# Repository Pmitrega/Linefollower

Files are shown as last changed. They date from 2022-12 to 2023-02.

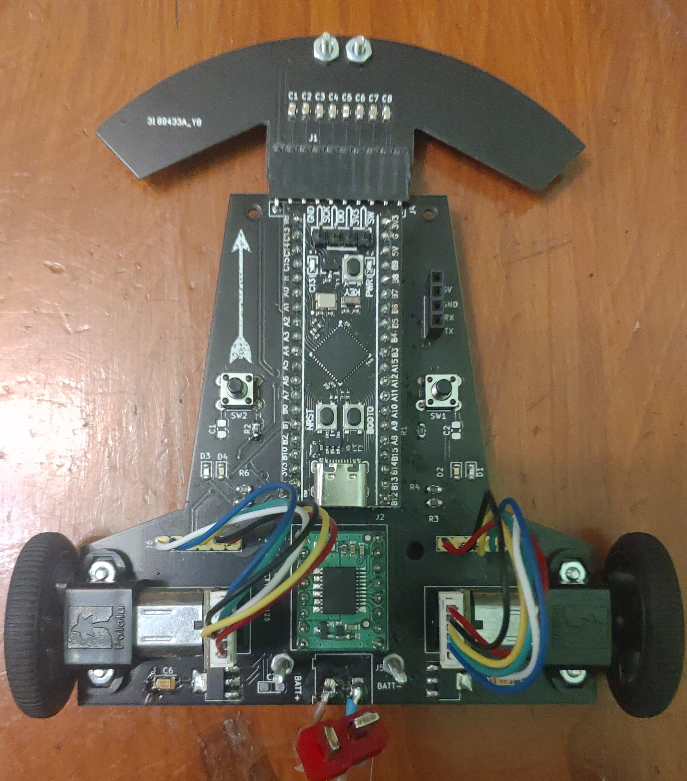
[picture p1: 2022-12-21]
photos/assembled.jpg

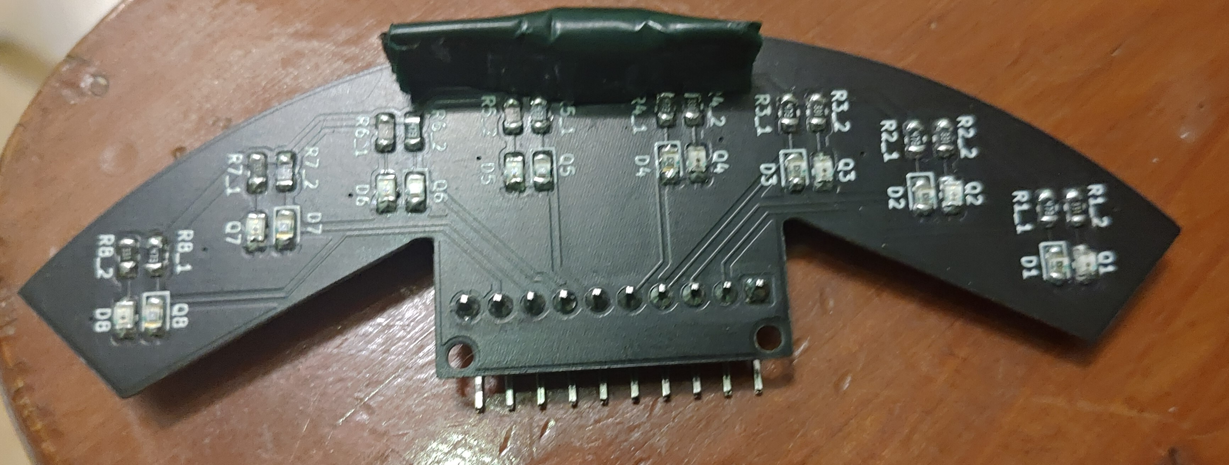
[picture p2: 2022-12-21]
photos/sensors.jpg

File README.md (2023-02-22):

# Linefollower
Robot is made on self-designed board with attached self-designed reflective sensors using ir diode and phototransistor.
For this moment there is algorithm estimating angle error, velocity control using PI controller, and angle P controller to follow line. Succesfully tested on track.
Can be also controlled using bluetooth with xbox controller by sending ascii commands.

Project is finnished, probably won't be updated. Contiunation of LF project is under this link: [Linefollower_V2](https://github.com/Pmitrega/Linefollower_V2)

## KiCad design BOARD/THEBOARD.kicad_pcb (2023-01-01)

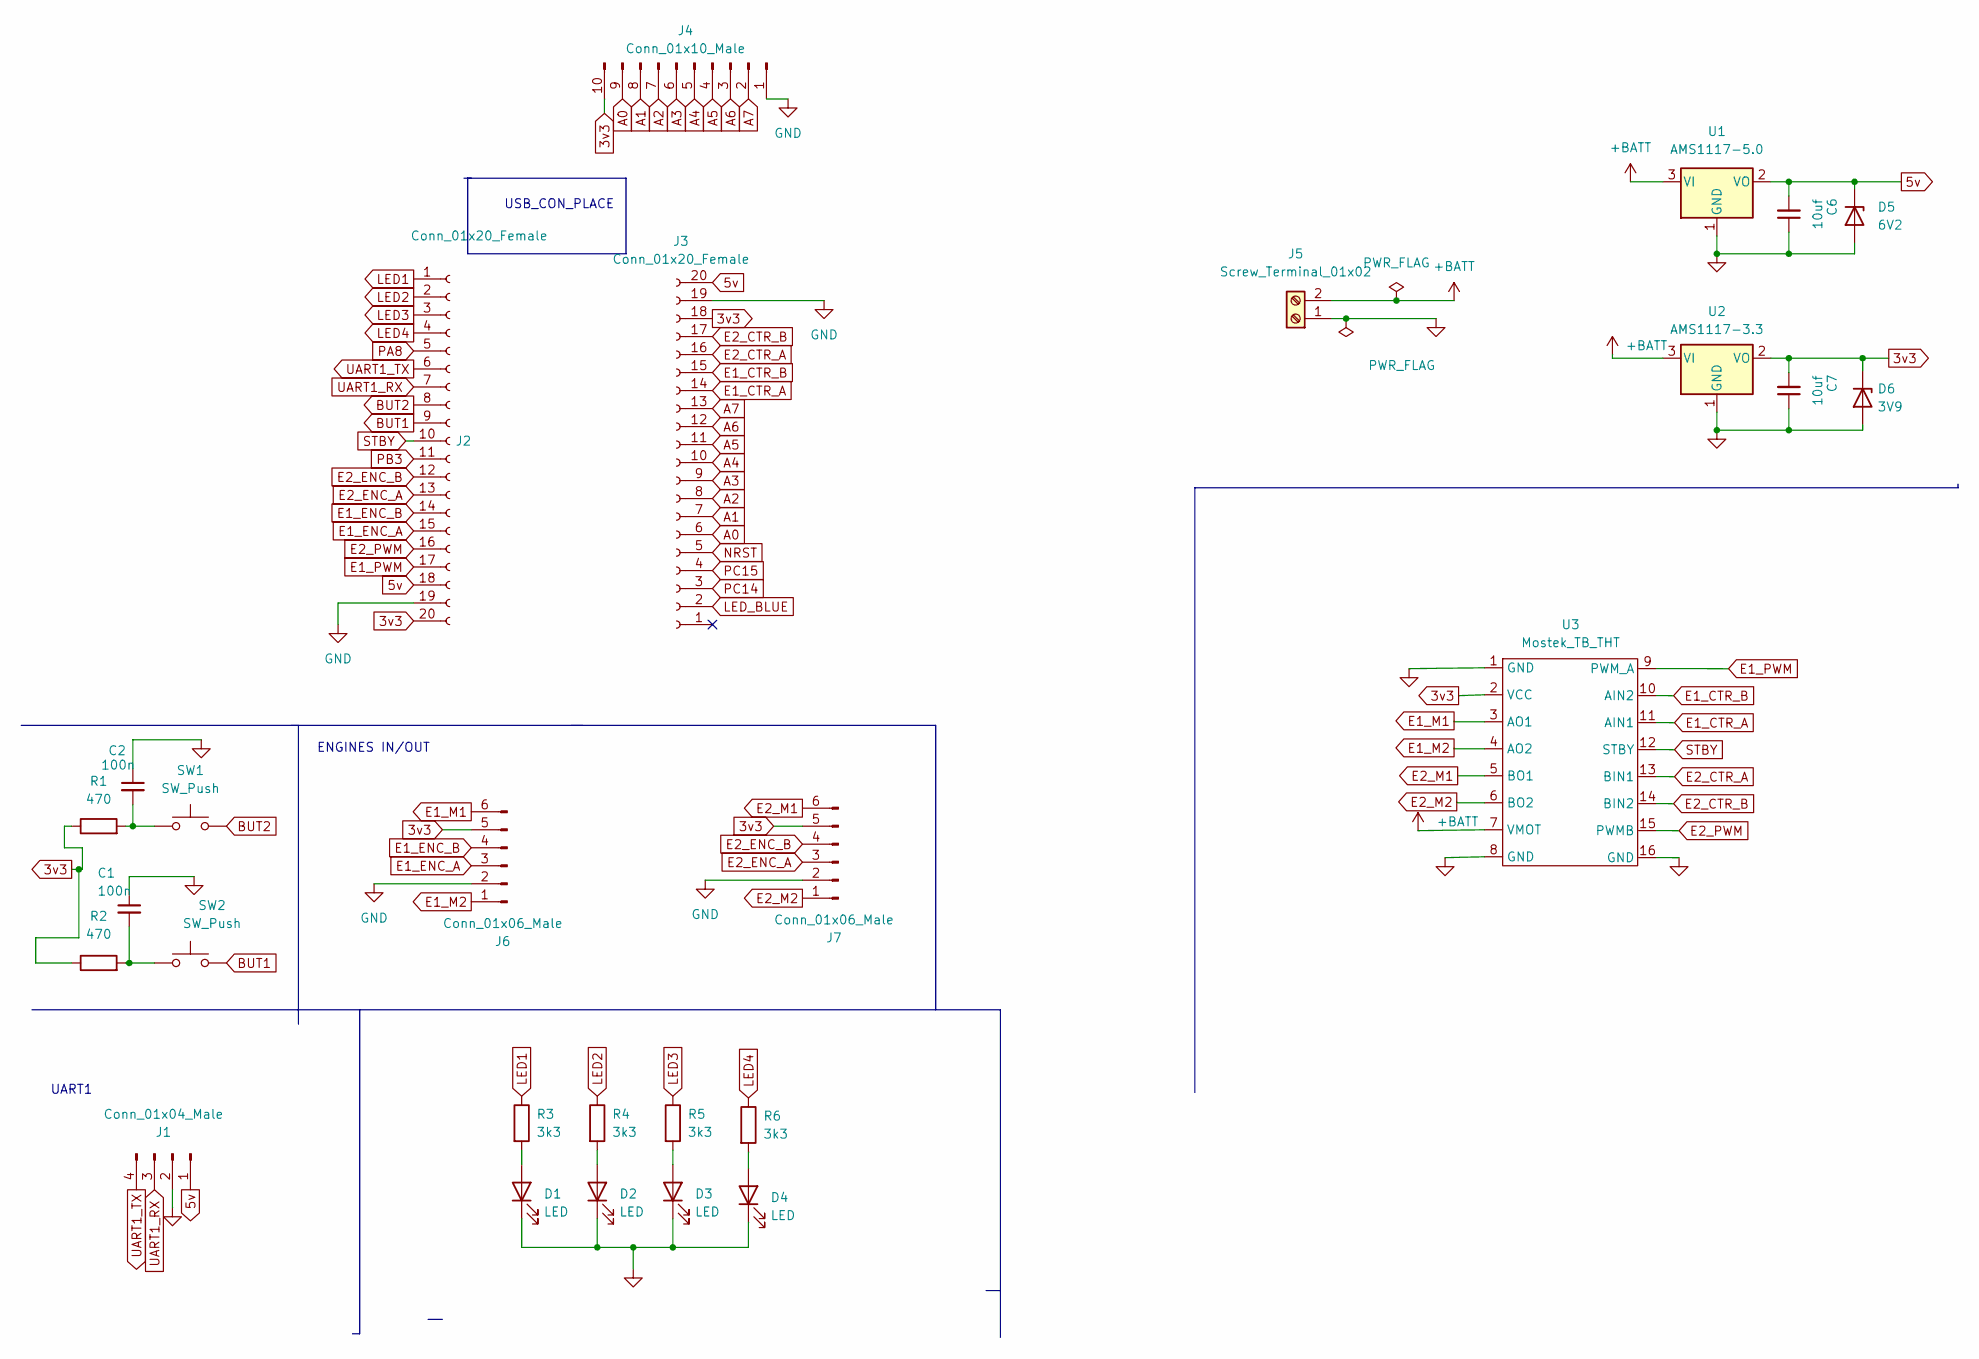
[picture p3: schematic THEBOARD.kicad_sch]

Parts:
C1, C2: 100n; C_0805_2012Metric_Pad1.18x1.45mm_HandSolder
C6, C7: 10uf; CP_EIA-3216-18_Kemet-A_Pad1.58x1.35mm_HandSolder
D1, D2, D3, D4: LED; D_0805_2012Metric_Pad1.15x1.40mm_HandSolder
D5: 6V2; D_MiniMELF_Handsoldering
D6: 3V9; D_MiniMELF_Handsoldering
J1: Conn_01x04_Male; PinSocket_1x04_P2.54mm_Vertical
J2, J3: Conn_01x20_Female; PinSocket_1x20_P2.54mm_Vertical
J4: Conn_01x10_Male; PinSocket_1x10_P2.54mm_Vertical
J5: Screw_Terminal_01x02; TerminalBlock_Altech_AK300-2_P5.00mm
J6, J7: Conn_01x06_Male; PinSocket_1x06_P2.54mm_Vertical
R1, R2: 470; R_0805_2012Metric_Pad1.20x1.40mm_HandSolder
R3, R4, R5, R6: 3k3; R_0805_2012Metric_Pad1.20x1.40mm_HandSolder
SW1, SW2: SW_Push; SW_PUSH_6mm
U1: AMS1117-5.0; SOT-223-3_TabPin2
U2: AMS1117-3.3; SOT-223-3_TabPin2
U3: Mostek_TB_THT; H_BRIDGE

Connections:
3v3: C7.2, D6.1 (K), J2.20, J3.18, J4.10, J6.5, J7.5, R1.1, R2.1, U2.2 (VO), U3.2 (VCC)
5v: C6.2, D5.1 (K), J1.1, J2.18, J3.20, U1.2 (VO)
+BATT: J5.2, U1.3 (VI), U2.3 (VI), U3.7 (VMOT); also elsewhere on the board
A0: J3.6, J4.9
A1: J3.7, J4.8
A2: J3.8, J4.7
A3: J3.9, J4.6
A4: J3.10, J4.5
A5: J3.11, J4.4
A6: J3.12, J4.3
A7: J3.13, J4.2
BUT1: J2.9, SW2.2
BUT2: J2.8, SW1.2
E1_CTR_A: J3.14, U3.11 (AIN1)
E1_CTR_B: J3.15, U3.10 (AIN2)
E1_ENC_A: J2.15, J6.3
E1_ENC_B: J2.14, J6.4
E1_M1: J6.6, U3.3 (AO1)
E1_M2: J6.1, U3.4 (AO2)
E1_PWM: J2.17, U3.9 (PWM_A)
E2_CTR_A: J3.16, U3.13 (BIN1)
E2_CTR_B: J3.17, U3.14 (BIN2)
E2_ENC_A: J2.13, J7.3
E2_ENC_B: J2.12, J7.4
E2_M1: J7.6, U3.5 (BO1)
E2_M2: J7.1, U3.6 (BO2)
E2_PWM: J2.16, U3.15 (PWMB)
GND: C1.1, C2.1, C6.1, C7.1, D1.1 (K), D2.1 (K), D3.1 (K), D4.1 (K), D5.2 (A), D6.2 (A), J1.2, J2.19, J3.19, J4.1, J5.1, J6.2, J7.2, U1.1 (GND), U2.1 (GND), U3.1 (GND), U3.8 (GND), U3.16 (GND); also elsewhere on the board
LED1: J2.1, R3.1
LED2: J2.2, R4.1
LED3: J2.3, R5.1
LED4: J2.4, R6.1
LED_BLUE: J3.2
NRST: J3.5
unnamed: C1.2, R2.2, SW2.1
unnamed: C2.2, R1.2, SW1.1
unnamed: D1.2 (A), R3.2
unnamed: D2.2 (A), R4.2
unnamed: D3.2 (A), R5.2
unnamed: D4.2 (A), R6.2
PA8: J2.5
PB3: J2.11
PC14: J3.3
PC15: J3.4
STBY: J2.10, U3.12 (STBY)
UART1_RX: J1.3, J2.7
UART1_TX: J1.4, J2.6

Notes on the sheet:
UART1
USB_CON_PLACE
ENGINES IN/OUT

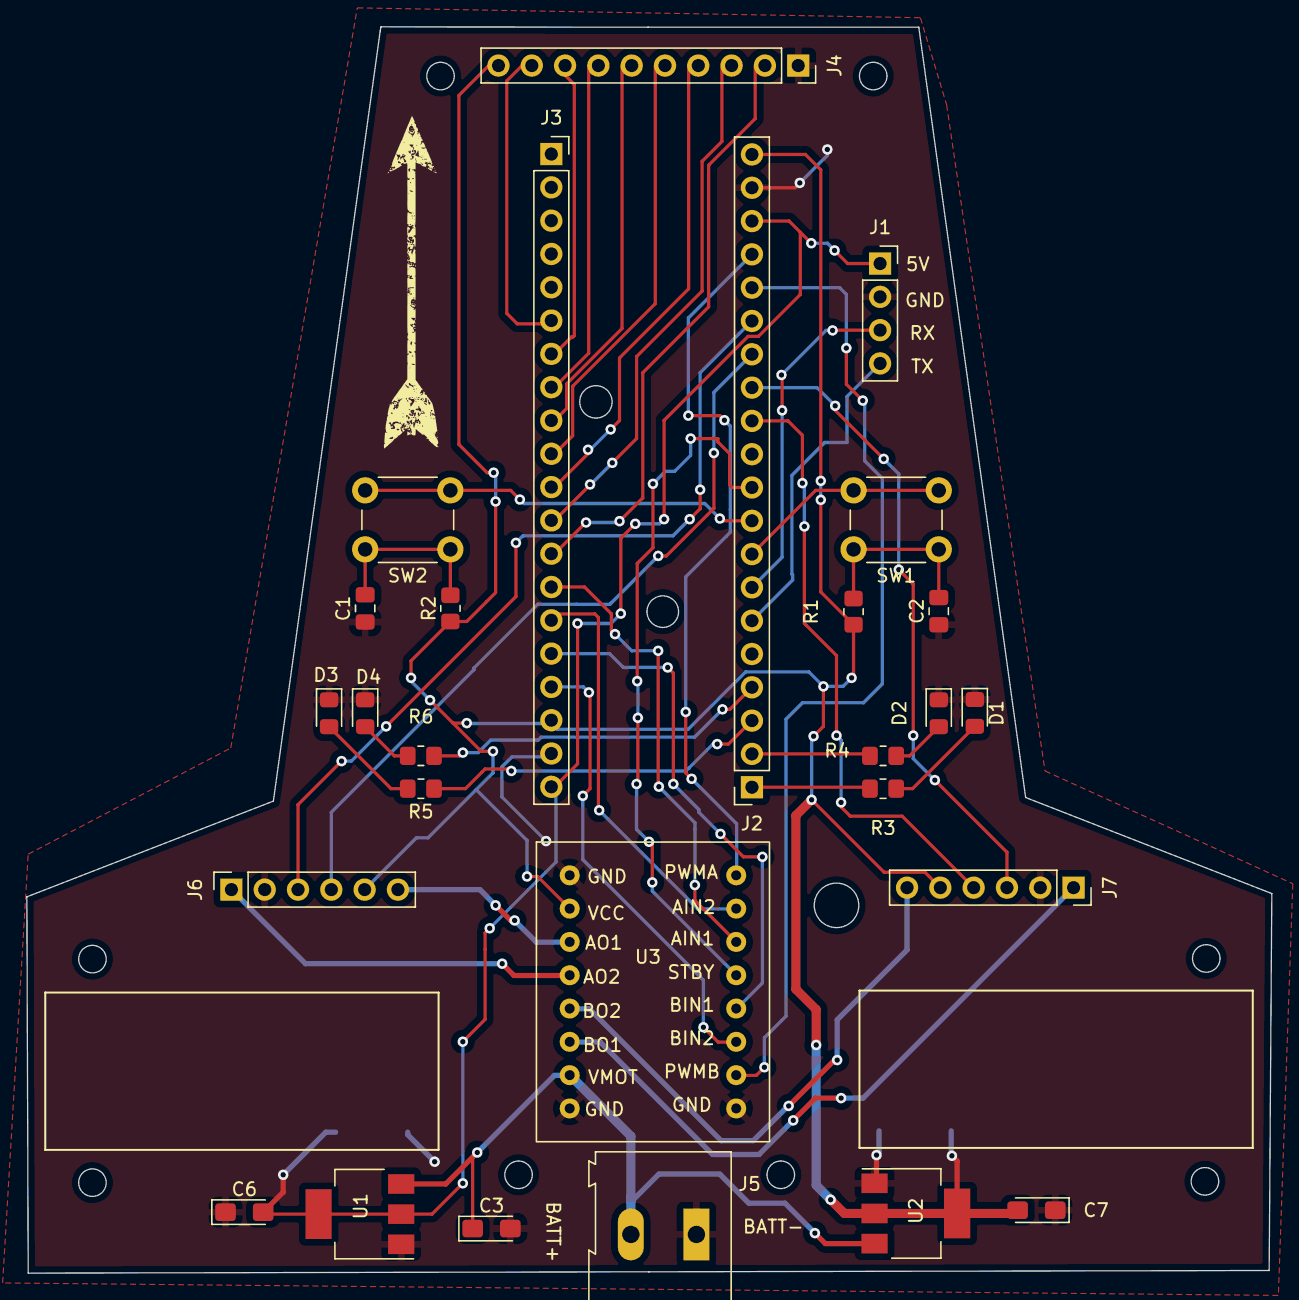
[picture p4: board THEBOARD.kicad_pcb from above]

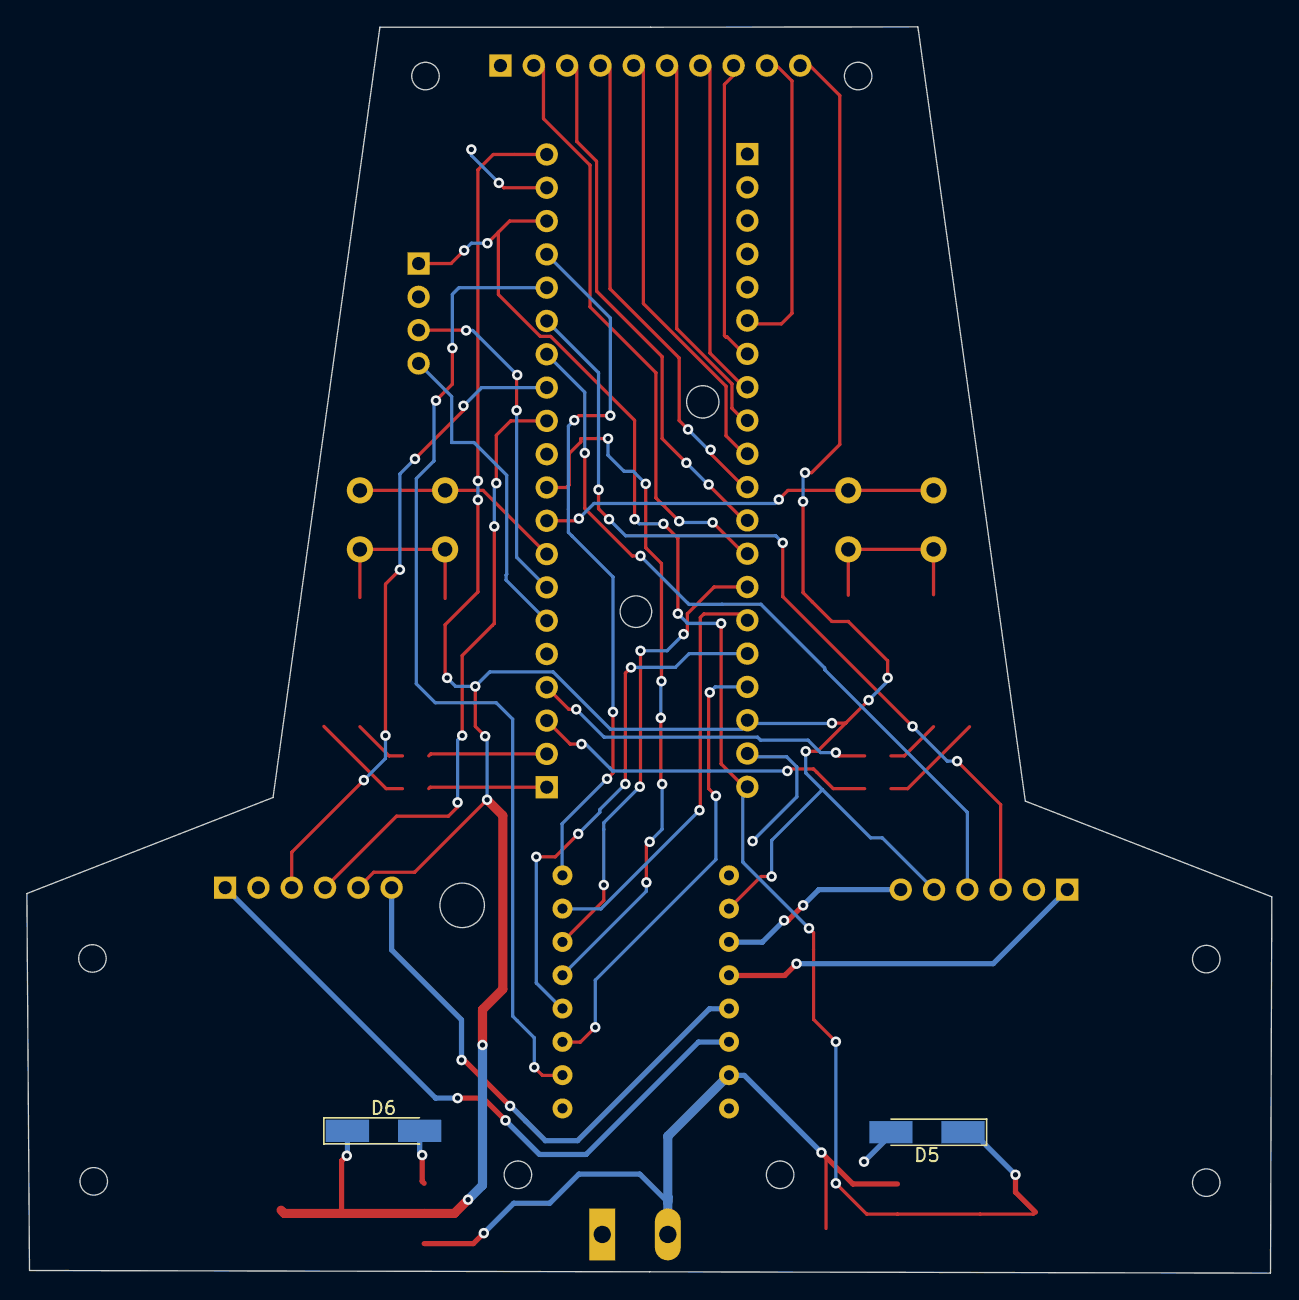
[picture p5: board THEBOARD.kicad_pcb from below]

Board: 2 copper layers, 95.0 x 95.0 mm, 29 parts (2 on the bottom side), 41 nets.

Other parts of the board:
C3: 10uf; CP_EIA-3216-18_Kemet-A_Pad1.58x1.35mm_HandSolder

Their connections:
+BATT: C3.1; also elsewhere on the board
GND: C3.2; also elsewhere on the board

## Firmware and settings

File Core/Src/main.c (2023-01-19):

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
/* Includes ------------------------------------------------------------------*/
#include "main.h"

/* USER CODE BEGIN Includes */
#include "motors.h"
#include "sensors.h"
#include "uart_handler.h"
/* USER CODE END Includes */

/* USER CODE BEGIN PD */
#define P_velocity 13

/* USER CODE END PD */

ADC_HandleTypeDef hadc1;
DMA_HandleTypeDef hdma_adc1;

TIM_HandleTypeDef htim3;
TIM_HandleTypeDef htim4;
TIM_HandleTypeDef htim5;
TIM_HandleTypeDef htim9;
TIM_HandleTypeDef htim10;
TIM_HandleTypeDef htim11;

UART_HandleTypeDef huart1;

/* USER CODE BEGIN PV */
int velocity_LEFT;
int velocity_RIGHT;
int velocity_ARRAY_LEFT[4] = {0,0,0,0};
int velocity_ARRAY_RIGHT[4] = {0,0,0,0};
int flt_cnt = 0;
extern uint16_t sensor_readings[8];
int angle = 0;
int BASE_SPEED = 0;
extern uint8_t recieve;
int auto_control_flag = 0;
/* USER CODE END PV */

void SystemClock_Config(void);
static void MX_GPIO_Init(void);
static void MX_DMA_Init(void);
static void MX_TIM10_Init(void);
static void MX_TIM11_Init(void);
static void MX_TIM3_Init(void);
static void MX_TIM4_Init(void);
static void MX_ADC1_Init(void);
static void MX_USART1_UART_Init(void);
static void MX_TIM9_Init(void);
static void MX_TIM5_Init(void);
/* USER CODE BEGIN 0 */

int get_average(int* arr,int size){
  int avr = 0;
  int div = size;
  for(int i=0;i<size;i++){
    if(arr[i]>2000){
      div--;
    }
    else
      avr+=arr[i];
  }
  return avr/div;
}
void HAL_TIM_PeriodElapsedCallback(TIM_HandleTypeDef *htim){
  static uint16_t last_enc_LEFT = 32000;
  static uint16_t last_enc_RIGHT = 32000;
  static int velocity_LEFT_TMP;
  static int velocity_RIGHT_TMP;
  if(htim == &htim9){
    velocity_LEFT = (int)(((int)last_enc_LEFT - ENCODER_LEFT)*CONVERSION_COEFFICIENT);
    velocity_RIGHT =(int)((-(int)last_enc_RIGHT + ENCODER_RIGHT)*CONVERSION_COEFFICIENT);
    // velocity_ARRAY_LEFT[flt_cnt%4] = velocity_LEFT_TMP;
    // velocity_ARRAY_RIGHT[flt_cnt%4] = velocity_RIGHT_TMP;
    // velocity_LEFT = get_average(velocity_ARRAY_LEFT, 4);
    // velocity_RIGHT = get_average(velocity_ARRAY_RIGHT, 4);
    // velocity_LEFT = velocity_LEFT_TMP;
    // velocity_LEFT = velocity_RIGHT_TMP;
    flt_cnt+=1;
    last_enc_LEFT = ENCODER_LEFT;
    last_enc_RIGHT = ENCODER_RIGHT;
  }
  if(htim == &htim5){
    if(auto_control_flag){
      angle = estimate_angle(sensor_readings);
      set_velocity(MOTOR_LEFT,P_velocity*angle+BASE_SPEED);
      set_velocity(MOTOR_RIGHT, -P_velocity*angle+BASE_SPEED);
  }
      velocity_pid();
  }
}

void led_check(){
  HAL_GPIO_WritePin(GPIOB, LED_RED1_Pin,1);
  HAL_Delay(200);
  HAL_GPIO_WritePin(GPIOB, LED_BLUE1_Pin, 1);
  HAL_Delay(200);
  HAL_GPIO_WritePin(GPIOB, LED_BLUE2_Pin, 1);
  HAL_Delay(200);
  HAL_GPIO_WritePin(GPIOB, LED_RED2_Pin, 1);
  HAL_Delay(200);
  HAL_GPIO_WritePin(GPIOB, LED_RED1_Pin,0);
  HAL_Delay(200);
  HAL_GPIO_WritePin(GPIOB, LED_BLUE1_Pin, 0);
  HAL_Delay(200);
  HAL_GPIO_WritePin(GPIOB, LED_BLUE2_Pin, 0);
  HAL_Delay(200);
  HAL_GPIO_WritePin(GPIOB, LED_RED2_Pin, 0);
}

/* USER CODE END 0 */

/**
  * @brief  The application entry point.
  * @retval int
  */
int main(void)
{
  /* MCU Configuration--------------------------------------------------------*/

  /* Reset of all peripherals, Initializes the Flash interface and the Systick. */
  HAL_Init();

  /* Configure the system clock */
  SystemClock_Config();

  /* Initialize all configured peripherals */
  MX_GPIO_Init();
  MX_DMA_Init();
  MX_TIM10_Init();
  MX_TIM11_Init();
  MX_TIM3_Init();
  MX_TIM4_Init();
  MX_ADC1_Init();
  MX_USART1_UART_Init();
  MX_TIM9_Init();
  MX_TIM5_Init();
  /* USER CODE BEGIN 2 */
  HAL_TIM_Base_Start_IT(&htim9);
  HAL_TIM_PWM_Start(&htim10, TIM_CHANNEL_1);
  HAL_TIM_PWM_Start(&htim11, TIM_CHANNEL_1);
  TIM3->CNT = 32000;
  TIM4->CNT = 32000;
  char buffer[30];
  int l;
  HAL_TIM_Encoder_Start(&htim3, TIM_CHANNEL_ALL);
  HAL_TIM_Encoder_Start(&htim4, TIM_CHANNEL_ALL);
  HAL_GPIO_WritePin(STBY_GPIO_Port, STBY_Pin, 1);
  HAL_GPIO_WritePin(STBY_GPIO_Port, STBY_Pin, 1);
  led_check();
  HAL_UART_Receive_IT(&huart1, &recieve, 1);
  HAL_ADC_Start_DMA(&hadc1,  (uint32_t *)sensor_readings, 8);
  HAL_Delay(200);
  HAL_TIM_Base_Start_IT(&htim5);

  /* USER CODE END 2 */

  /* Infinite loop */
  /* USER CODE BEGIN WHILE */
  while (1)
  {   
      HAL_Delay(300);
      if(HAL_GPIO_ReadPin(SW2_GPIO_Port, SW2_Pin)){
        auto_control_flag = 1;
        BASE_SPEED = 120;
      }
      //l = sprintf(buffer, "%d %d %d %d %d %d %d %d\n",sensor_readings[0],sensor_readings[1],sensor_readings[2],sensor_readings[3],sensor_readings[4],sensor_readings[5],sensor_readings[6],sensor_readings[7]);
      // l = sprintf(buffer, "%d %d %d\n", velocity_LEFT, velocity_RIGHT, estimate_angle(sensor_readings));
      // HAL_UART_Transmit(&huart1, buffer, l, 100);
      //HAL_Delay(3);
    /* USER CODE END WHILE */

    /* USER CODE BEGIN 3 */
  }
  /* USER CODE END 3 */
}

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


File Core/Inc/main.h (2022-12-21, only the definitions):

#define LED_ONBOARD_Pin GPIO_PIN_13
#define LED_ONBOARD_GPIO_Port GPIOC
#define AIN1_Pin GPIO_PIN_0
#define AIN1_GPIO_Port GPIOB
#define AIN2_Pin GPIO_PIN_1
#define AIN2_GPIO_Port GPIOB
#define BIN1_Pin GPIO_PIN_2
#define BIN1_GPIO_Port GPIOB
#define BIN2_Pin GPIO_PIN_10
#define BIN2_GPIO_Port GPIOB
#define LED_RED2_Pin GPIO_PIN_12
#define LED_RED2_GPIO_Port GPIOB
#define LED_BLUE2_Pin GPIO_PIN_13
#define LED_BLUE2_GPIO_Port GPIOB
#define LED_RED1_Pin GPIO_PIN_14
#define LED_RED1_GPIO_Port GPIOB
#define LED_BLUE1_Pin GPIO_PIN_15
#define LED_BLUE1_GPIO_Port GPIOB
#define SW1_Pin GPIO_PIN_11
#define SW1_GPIO_Port GPIOA
#define SW2_Pin GPIO_PIN_12
#define SW2_GPIO_Port GPIOA
#define STBY_Pin GPIO_PIN_15
#define STBY_GPIO_Port GPIOA
#define PWMB_Pin GPIO_PIN_8
#define PWMB_GPIO_Port GPIOB
#define PWMA_Pin GPIO_PIN_9
#define PWMA_GPIO_Port GPIOB

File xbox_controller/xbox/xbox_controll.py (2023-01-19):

import time
import serial
from inputs import get_gamepad
import math
import threading

class XboxController(object):
    MAX_TRIG_VAL = math.pow(2, 8)
    MAX_JOY_VAL = math.pow(2, 15)

    def __init__(self):

        self.LeftJoystickY = 0
        self.LeftJoystickX = 0
        self.RightJoystickY = 0
        self.RightJoystickX = 0
        self.LeftTrigger = 0
        self.RightTrigger = 0
        self.LeftBumper = 0
        self.RightBumper = 0
        self.A = 0
        self.X = 0
        self.Y = 0
        self.B = 0
        self.LeftThumb = 0
        self.RightThumb = 0
        self.Back = 0
        self.Start = 0
        self.LeftDPad = 0
        self.RightDPad = 0
        self.UpDPad = 0
        self.DownDPad = 0

        self._monitor_thread = threading.Thread(target=self._monitor_controller, args=())
        self._monitor_thread.daemon = True
        self._monitor_thread.start()


    def read(self): # return the buttons/triggers that you care about in this methode
        x = self.LeftJoystickX
        y = self.LeftJoystickY
        a = self.RightJoystickY
        b = self.RightJoystickX
        return [x, y, a, b]


    def _monitor_controller(self):
        while True:
            events = get_gamepad()
            for event in events:
                if event.code == 'ABS_Y':
                    self.LeftJoystickY = event.state / XboxController.MAX_JOY_VAL # normalize between -1 and 1
                elif event.code == 'ABS_X':
                    self.LeftJoystickX = event.state / XboxController.MAX_JOY_VAL # normalize between -1 and 1
                elif event.code == 'ABS_RY':
                    self.RightJoystickY = event.state / XboxController.MAX_JOY_VAL # normalize between -1 and 1
                elif event.code == 'ABS_RX':
                    self.RightJoystickX = event.state / XboxController.MAX_JOY_VAL # normalize between -1 and 1
                elif event.code == 'ABS_Z':
                    self.LeftTrigger = event.state / XboxController.MAX_TRIG_VAL # normalize between 0 and 1
                elif event.code == 'ABS_RZ':
                    self.RightTrigger = event.state / XboxController.MAX_TRIG_VAL # normalize between 0 and 1
                elif event.code == 'BTN_TL':
                    self.LeftBumper = event.state
                elif event.code == 'BTN_TR':
                    self.RightBumper = event.state
                elif event.code == 'BTN_SOUTH':
                    self.A = event.state
                elif event.code == 'BTN_NORTH':
                    self.Y = event.state #previously switched with X
                elif event.code == 'BTN_WEST':
                    self.X = event.state #previously switched with Y
                elif event.code == 'BTN_EAST':
                    self.B = event.state
                elif event.code == 'BTN_THUMBL':
                    self.LeftThumb = event.state
                elif event.code == 'BTN_THUMBR':
                    self.RightThumb = event.state
                elif event.code == 'BTN_SELECT':
                    self.Back = event.state
                elif event.code == 'BTN_START':
                    self.Start = event.state
                elif event.code == 'BTN_TRIGGER_HAPPY1':
                    self.LeftDPad = event.state
                elif event.code == 'BTN_TRIGGER_HAPPY2':
                    self.RightDPad = event.state
                elif event.code == 'BTN_TRIGGER_HAPPY3':
                    self.UpDPad = event.state
                elif event.code == 'BTN_TRIGGER_HAPPY4':
                    self.DownDPad = event.state


'''
Here base velocity parameters are set
'''
BASE_VELOCITY = 80
BASE_TURN_VELOCITY = 40

if __name__ == '__main__':
    joy = XboxController()
    ser = serial.Serial('COM5', 9600, timeout = 6)
    while True:
        '''
        values are are taken from right joystick - up and down is linear velocity - right and left is turning speed
        '''
        cmd = ""
        cmd = cmd+"l" + str(int(BASE_VELOCITY*joy.read()[2]) + BASE_TURN_VELOCITY*joy.read()[3]) + "r" + str(int(BASE_VELOCITY*joy.read()[2]) - BASE_TURN_VELOCITY*joy.read()[3]) + " "
        ser.write(cmd.encode())
        if joy.A == 1:
            '''
            Here is command to change to automatic mode with base speed of 120. LF start following line. This command can be sent again to go back to manual mode.
            sleep prevents from sending multiple time this command.
            '''
            ser.write("a120 ".encode())
            time.sleep(0.3)
        time.sleep(0.03)
        # while ser.in_waiting:
        #     print(ser.readline())

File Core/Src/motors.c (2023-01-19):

#include "motors.h"
#include "string.h"
#include "stdio.h"
#include "main.h"
extern UART_HandleTypeDef huart1;
extern int velocity_LEFT;
extern int velocity_RIGHT;
int desired_velocity_left;
int desired_velocity_right;
int set_PWM(enum Motor mot, uint16_t value){
    if(value>1000){
        return -1;
    }
    if(mot == MOTOR_LEFT){
        TIM11->CCR1 = value;
    }
    else if (mot == MOTOR_RIGHT)
    {
        TIM10->CCR1 = value;
    }
    return 0;
    
}
int set_direction(enum Motor mot,enum Direction dir){

    if(mot == MOTOR_LEFT){
        if(dir == BACKWARD){
            HAL_GPIO_WritePin(AIN1_GPIO_Port, AIN1_Pin, 1);
            HAL_GPIO_WritePin(AIN1_GPIO_Port, AIN2_Pin, 0);
        }
        else if(dir == FORWARD){
            HAL_GPIO_WritePin(AIN1_GPIO_Port, AIN1_Pin, 0);
            HAL_GPIO_WritePin(AIN1_GPIO_Port, AIN2_Pin, 1);
        }
    }
    else if(mot == MOTOR_RIGHT){
        if(dir == BACKWARD){
            HAL_GPIO_WritePin(AIN1_GPIO_Port, BIN1_Pin, 1);
            HAL_GPIO_WritePin(AIN1_GPIO_Port, BIN2_Pin, 0);
        }
        else if(dir == FORWARD){
            HAL_GPIO_WritePin(AIN1_GPIO_Port, BIN1_Pin, 0);
            HAL_GPIO_WritePin(AIN1_GPIO_Port, BIN2_Pin, 1);
        }
    }
    return 0;
};

void test_engine(enum Motor mot){
    uint16_t pwm_value = 0;
    static char buffer[20];
    int l;
    set_direction(mot, FORWARD);
    for(int i = 0; i<100; i+=1){
        set_PWM(mot, pwm_value);
        l = sprintf(buffer, "%d %d \n",pwm_value,mot == MOTOR_LEFT ? velocity_LEFT:velocity_RIGHT);
        HAL_UART_Transmit(&huart1, buffer, l, 100);
        pwm_value+=10;
        HAL_Delay(500);
    } 
    set_PWM(mot, 0);
}
int calc_velocity(uint16_t last_enc_reading, uint16_t enc_reading);
int set_control(enum Motor mot, int16_t value){
    //SATURATION
    if(value > 1000)
        value = 1000;
    if(value < -1000)
        value = -1000;

    if (value < 0)
        set_direction(mot, BACKWARD);
    else
        set_direction(mot, FORWARD);
    if(value < 0)
        value = -value;
    
    set_PWM(mot, value);

};

void test_step_engine(enum Motor mot){
    uint16_t pwm_value = 1000;
    char buffer[20];
    int l;
    set_direction(mot, FORWARD);
    set_PWM(mot, pwm_value);
    set_direction(MOTOR_RIGHT, FORWARD);
    set_PWM(MOTOR_RIGHT, pwm_value);
    for(int i = 0; i<100; i+=1){
        l = sprintf(buffer, "%d %d \n",velocity_LEFT,velocity_RIGHT);
        HAL_UART_Transmit(&huart1, buffer, l, 100);
        HAL_Delay(4);
    } 
    set_PWM(MOTOR_LEFT, 0);
    set_PWM(MOTOR_RIGHT, 0);
}

void print_encoders(){
    int lenght;
    char buffer[20];
    lenght = sprintf(buffer, "%d %d\n",ENCODER_LEFT, ENCODER_RIGHT);
    HAL_UART_Transmit(&huart1, buffer, lenght, 100);
}
void pid_left(int error, int point_of_work){
static int last_point_of_work = 0;
    static int error_integral = 0;
    if(last_point_of_work != point_of_work){
        error_integral = 0;
        error = 0;
    }
    last_point_of_work = point_of_work;
    error_integral+= error;
    if(error_integral > 200)error_integral =200;
    if(error_integral < -200)error_integral = -200;
    int base_value = point_of_work * 4;
    float P = 5;
    float I = 1;
    set_control(MOTOR_LEFT, base_value + error * P+ error_integral * I);
}
void pid_right(int error, int point_of_work){
    static int last_point_of_work = 0;
    static int error_integral = 0;
    if(last_point_of_work != point_of_work){
        error_integral = 0;
        error = 0;
    }
    last_point_of_work = point_of_work;
    error_integral+= error;
    if(error_integral > 200)error_integral =200;
    if(error_integral < -200)error_integral = -200;
    int base_value = point_of_work * 4;
    float P = 5;
    float I = 1;
    set_control(MOTOR_RIGHT, base_value + error * P+ error_integral * I);
}
void velocity_pid(){
    pid_left(desired_velocity_left - velocity_LEFT, desired_velocity_left);
    pid_right(desired_velocity_right - velocity_RIGHT, desired_velocity_right);
}

void set_velocity(enum Motor mot, int desired_velocity){
    if(mot == MOTOR_RIGHT){
        desired_velocity_right = desired_velocity;
    }
    if(mot == MOTOR_LEFT){
        desired_velocity_left = desired_velocity;
    }
}

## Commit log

2022-12-18 Added PWM control of engines and encoder readings
2022-12-21 motors pid
2022-12-21 motor PID
2022-12-21 Better controller, going much faster, fixed out of range angle estimation (keeps last value, when there is no sensor detection)
    [lf.ioc, main.c, sensors.h]
2023-01-01 board schematics
    [THEBOARD.kicad_pcb, THEBOARD.kicad_sch]
2023-01-19 added blutooth wireless controll + app for xbox controller ( can be moved by joystick and automatic controll can be turend on/off pressing A)

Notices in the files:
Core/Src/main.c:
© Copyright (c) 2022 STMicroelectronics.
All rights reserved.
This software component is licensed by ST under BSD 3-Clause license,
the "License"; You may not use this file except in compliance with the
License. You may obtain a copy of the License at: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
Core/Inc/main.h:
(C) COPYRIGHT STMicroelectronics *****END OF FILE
